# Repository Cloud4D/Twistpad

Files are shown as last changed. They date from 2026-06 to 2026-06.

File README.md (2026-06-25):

#  Twistpad
My submission for the Hack Club Hackpad project.

This repository contains all the files needed to produce a Twistpad, created by me. The Twistpad consists of a 3x3 grid of standard keys, which are bound to F13 - F21. On the right side of the grid, there are two dials, and the top one is bound to volume while the bottom one is bound to video controls (forward, backward, etc.). Additionally, there are LEDs, because who doesn't like a little RGB? I created this project over the course of nearly two weeks, using KiCad for the PCB, Fusion360 for the case design, and VSCode and Python for the firmware. 

So without further adieu, I present... the Twistpad!

## The hackpad:
A wonderful side view to give you an idea of the height



And then a top view so you can look through the window in the top right! (that tiny thing took me quite a long time)



The hackpad consists of a simple case design, with filleted corners and cutouts in the top to provide psace for the keys and dials to poke through. I wanted to add some extra stuff, so I spend time on the USB cutout (pictured below) making it look good and having it have a little inwards slant. i also spend time making the window into the PCB, which displays the Seeeduino logo perfectly. 



## Schematic of the PCB:
Made on KiCad, it was quite fun and easy to make it, no need to worry about physical space and stuff. 



The glorious PCB itself:
Also made on KiCad, it was also fun to do this, once I learned about vias. Has thicker traces for the 5V lines. 



## The case itself
This image pictures both the top plate and bottom part of the case, seperated. They fit together using M3x16mm screws along with M3x5mx4mm heatset inserts through the 4 holes on each corner of the case. In total, there are only 2 printed parts, the top and the bottom.



## The Firmware
This hackpad uses KMK firmware, and it was coded on VSCode using Python. 

## The BOM
1x Seeed XIAO RP2040

11x through-hold 1N4148 Diodes

9x MX-Style Switches

2x EC11 Rotary Encoders

9x white (or really any color or design you want) DSA keycaps

9x SK6812 MINI-E LEDs

4x M3x16mm screws

4x M3x5mx4mm heatset inserts

## Controls and binds
Imagine a 3x3 grid

A B C

D E F

G H I

Key A is bound to F13

Key B is bound to F14

Key C is bound to F15

Key D is bound to F16

Key E is bound to F17

Key F is bound to F18

Key G is bound to F19

Key H is bound to F20

Key I is bound to F21

In addition to that, due to a lack of pins, clicking down on the top dial is also mapped to whatever Key C is mapped to, and clicking down on the bottom dial is mapped to whatever Key I is mapped to.
Turning the top dial controls the volume, and turning the bottom dial controls video progress, like going forward in the video or backwards.

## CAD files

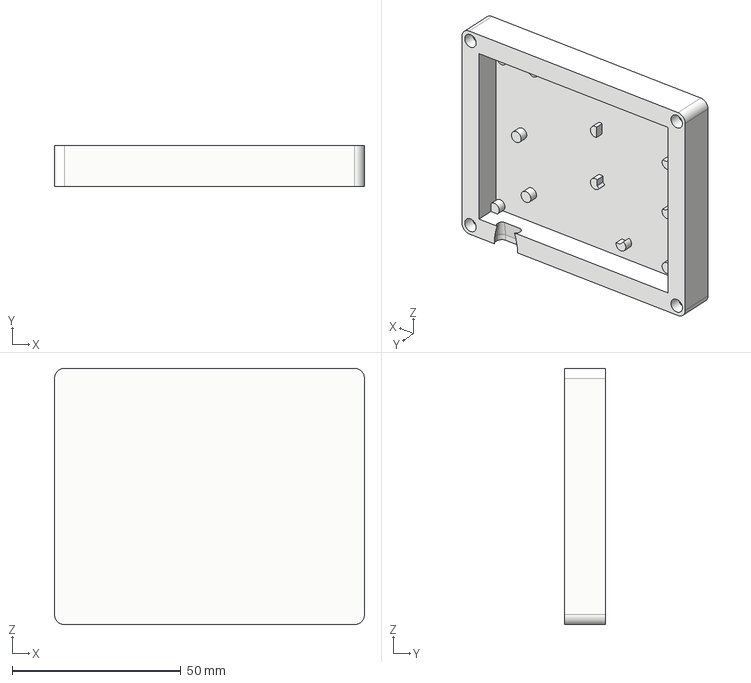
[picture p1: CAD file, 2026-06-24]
bottom.step
91.9 x 12.0 x 76.0 mm

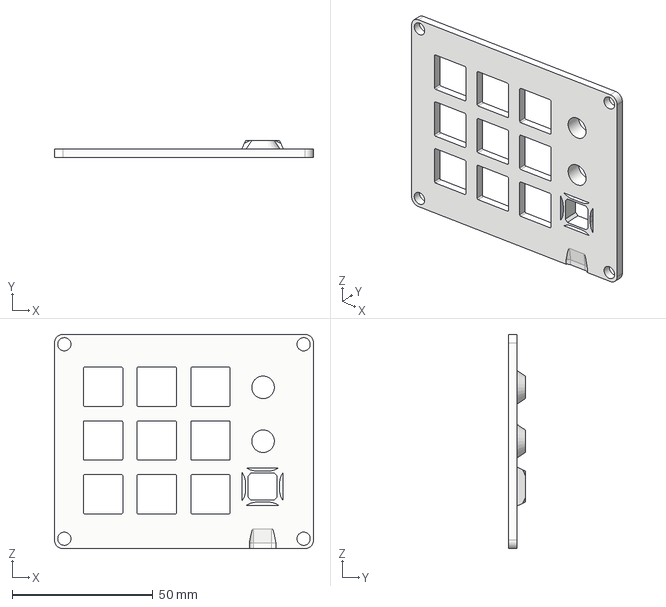
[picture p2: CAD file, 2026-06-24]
top.step
91.8 x 6.00 x 76.0 mm

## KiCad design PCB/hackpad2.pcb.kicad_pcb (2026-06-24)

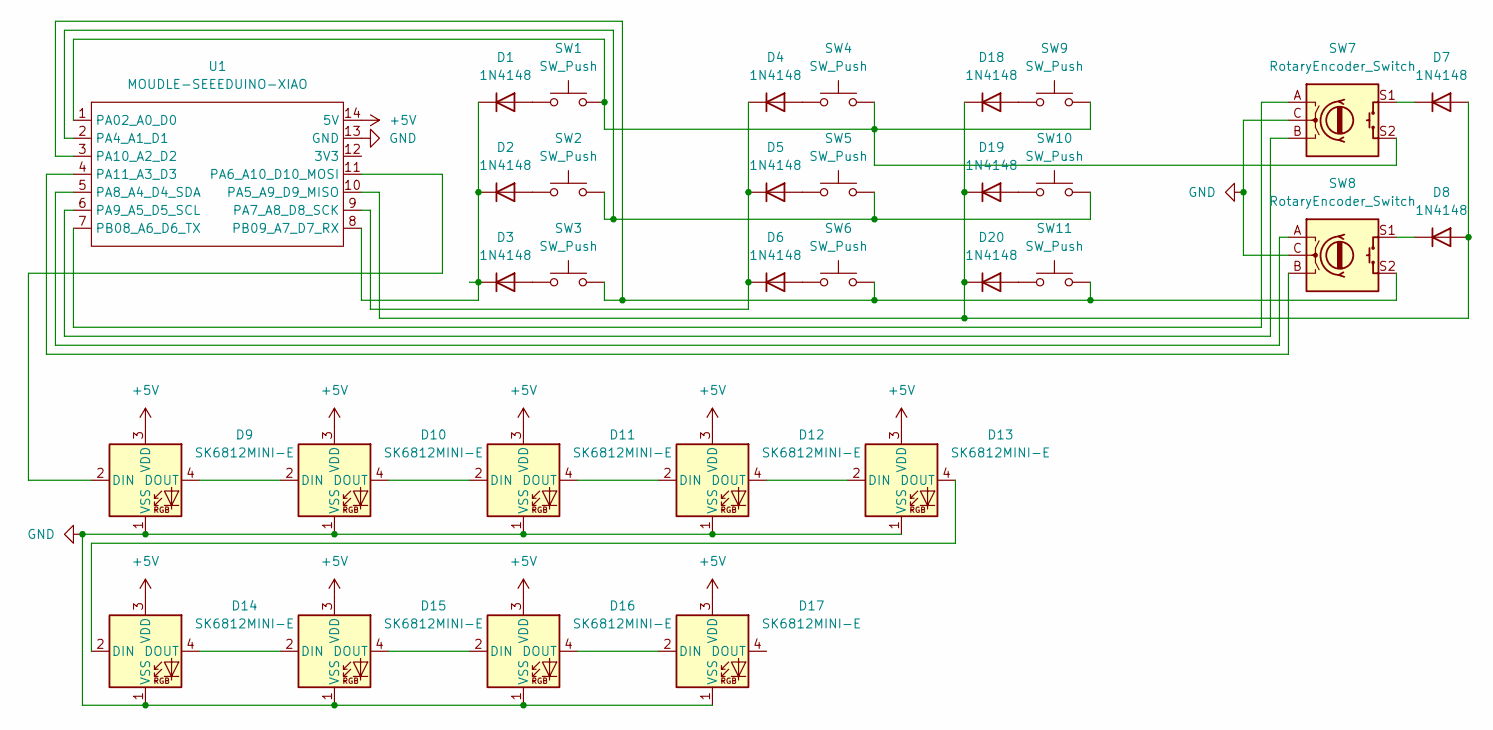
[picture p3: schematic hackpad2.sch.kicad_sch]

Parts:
D1, D2, D3, D4, D5, D6, D7, D8, D18, D19, D20: 1N4148; D_DO-35_SOD27_P7.62mm_Horizontal
D9, D10, D11, D12, D13, D14, D15, D16, D17: SK6812MINI-E; SK6812MINI-E_fixed
SW1, SW2, SW3, SW4, SW5, SW6, SW9, SW10, SW11: SW_Push; SW_Cherry_MX_1.00u_PCB
SW7, SW8: RotaryEncoder_Switch; RotaryEncoder_Alps_EC11E-Switch_Vertical_H20mm
U1: MOUDLE-SEEEDUINO-XIAO; XIAO-Generic-Hybrid-14P-2.54-21X17.8MM

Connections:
+5V: D9.3 (VDD), D10.3 (VDD), D11.3 (VDD), D12.3 (VDD), D13.3 (VDD), D14.3 (VDD), D15.3 (VDD), D16.3 (VDD), D17.3 (VDD), U1.14 (5V)
GND: D9.1 (VSS), D10.1 (VSS), D11.1 (VSS), D12.1 (VSS), D13.1 (VSS), D14.1 (VSS), D15.1 (VSS), D16.1 (VSS), D17.1 (VSS), SW7.C, SW8.C, U1.13 (GND)
unnamed: D1.2 (A), SW1.1
unnamed: D1.1 (K), D2.1 (K), D3.1 (K), U1.8 (PB09_A7_D7_RX)
unnamed: D2.2 (A), SW2.1
unnamed: D3.2 (A), SW3.1
unnamed: D4.2 (A), SW4.1
unnamed: D4.1 (K), D5.1 (K), D6.1 (K), U1.9 (PA7_A8_D8_SCK)
unnamed: D5.2 (A), SW5.1
unnamed: D6.2 (A), SW6.1
unnamed: D7.1 (K), SW7.S1
unnamed: D8.1 (K), SW8.S1
unnamed: D9.2 (DIN), U1.11 (PA6_A10_D10_MOSI)
unnamed: D9.4 (DOUT), D10.2 (DIN)
unnamed: D10.4 (DOUT), D11.2 (DIN)
unnamed: D11.4 (DOUT), D12.2 (DIN)
unnamed: D12.4 (DOUT), D13.2 (DIN)
unnamed: D13.4 (DOUT), D14.2 (DIN)
unnamed: D14.4 (DOUT), D15.2 (DIN)
unnamed: D15.4 (DOUT), D16.2 (DIN)
unnamed: D16.4 (DOUT), D17.2 (DIN)
unnamed: D18.2 (A), SW9.1
unnamed: D7.2 (A), D8.2 (A), D18.1 (K), D19.1 (K), D20.1 (K), U1.10 (PA5_A9_D9_MISO)
unnamed: D19.2 (A), SW10.1
unnamed: D20.2 (A), SW11.1
unnamed: SW1.2, SW4.2, SW7.S2, SW9.2, U1.1 (PA02_A0_D0)
unnamed: SW2.2, SW5.2, SW10.2, U1.2 (PA4_A1_D1)
unnamed: SW8.A, U1.5 (PA8_A4_D4_SDA)
unnamed: SW7.B, U1.6 (PA9_A5_D5_SCL)
unnamed: SW3.2, SW6.2, SW8.S2, SW11.2, U1.3 (PA10_A2_D2)
unnamed: SW8.B, U1.4 (PA11_A3_D3)
unnamed: SW7.A, U1.7 (PB08_A6_D6_TX)

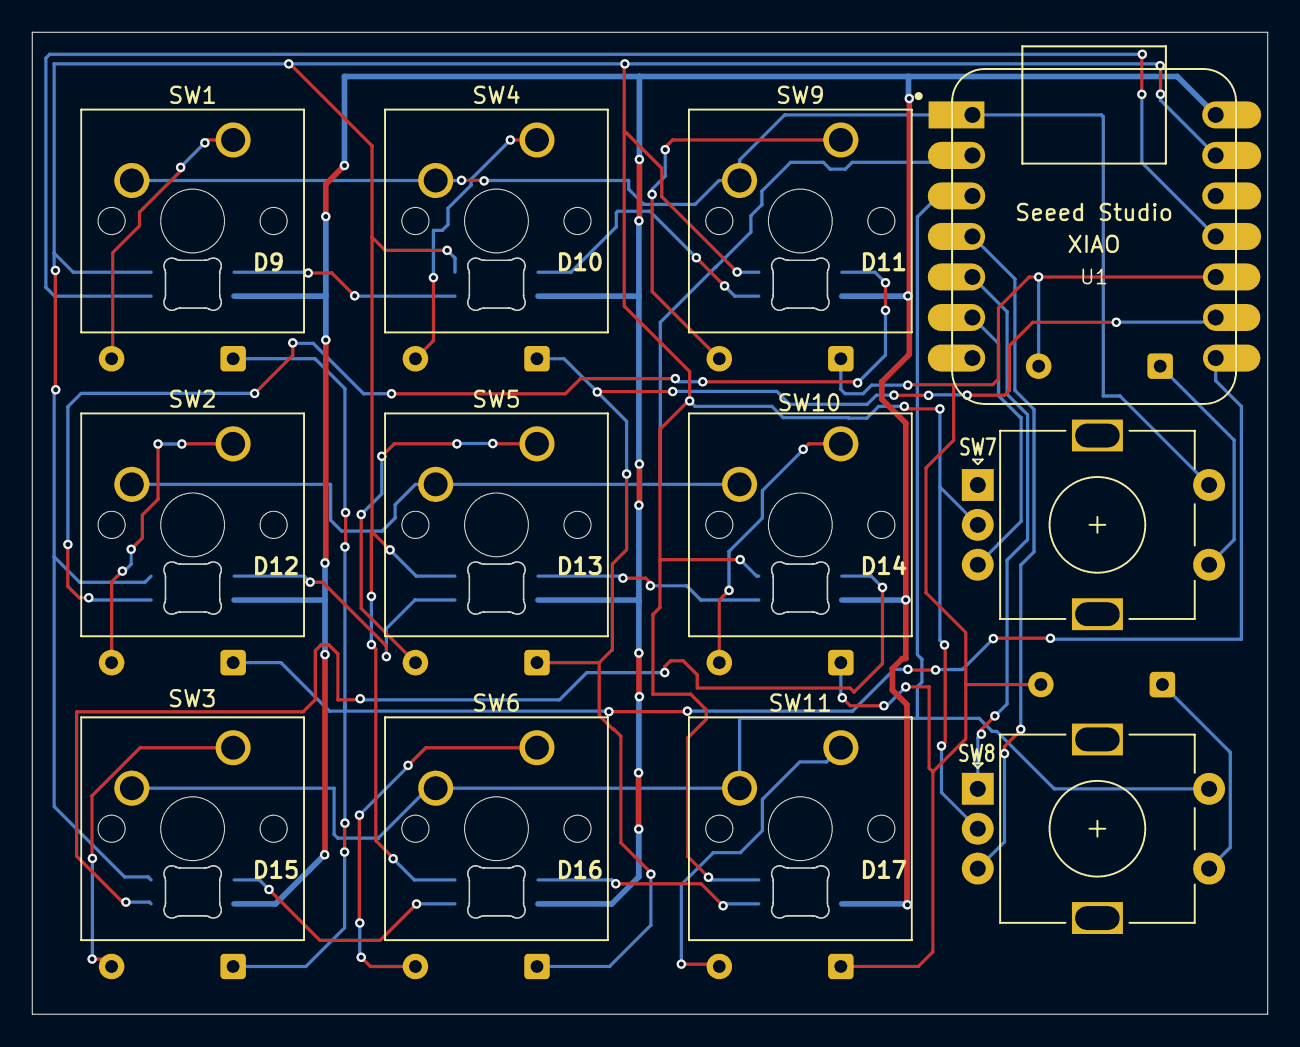
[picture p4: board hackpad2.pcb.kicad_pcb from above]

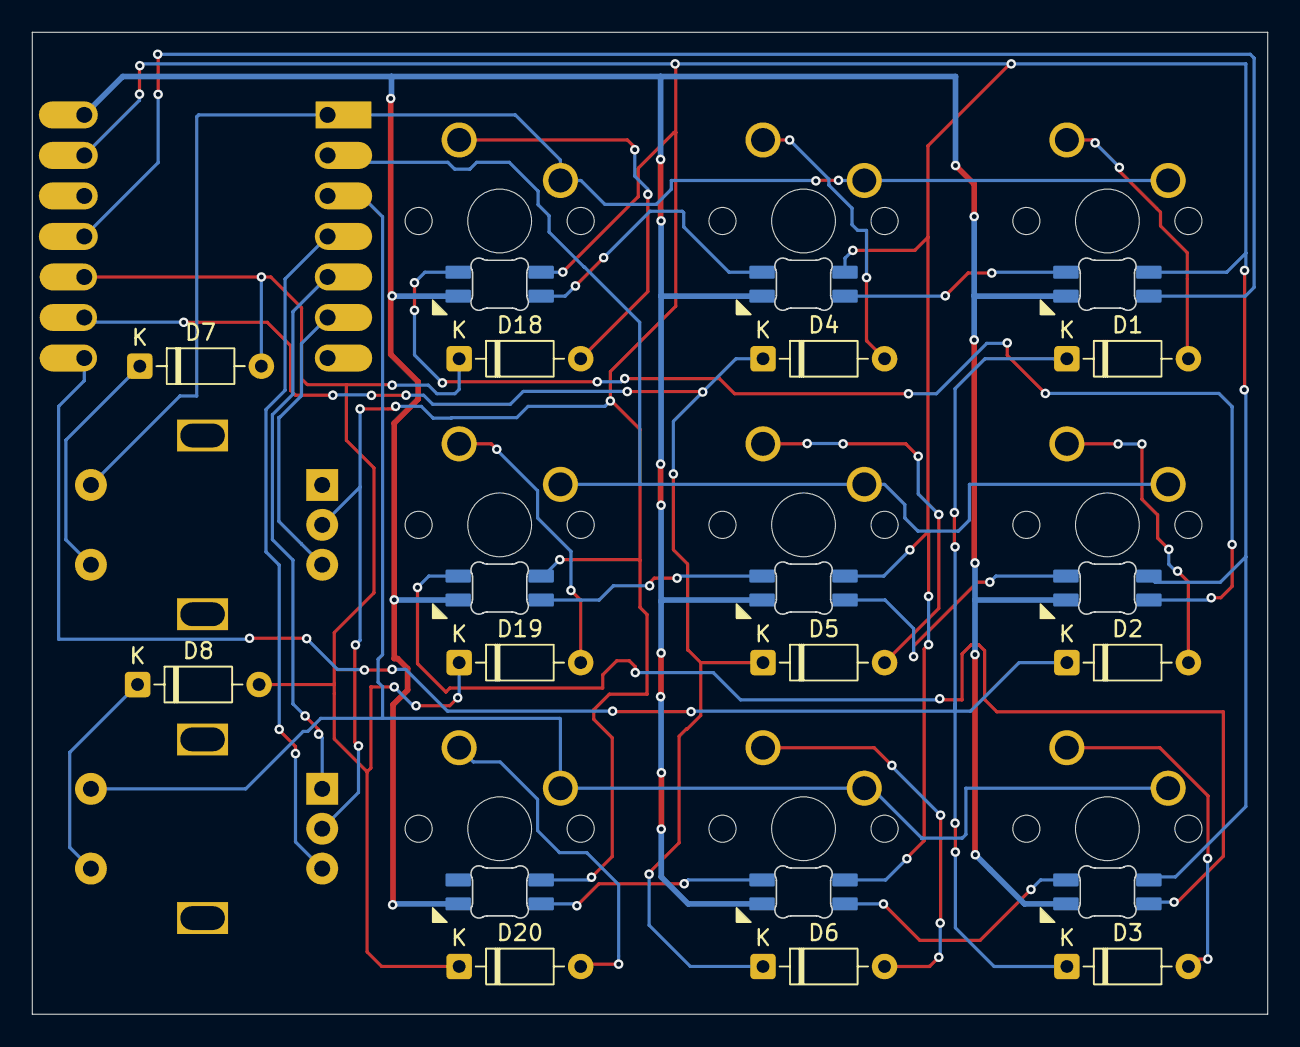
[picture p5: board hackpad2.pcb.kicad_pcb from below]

Board: 2 copper layers, 77.4 x 61.6 mm, 32 parts (11 on the bottom side), 32 nets.

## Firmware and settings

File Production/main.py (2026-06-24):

import board
from kmk.kmk_keyboard import KMKKeyboard
from kmk.keys import KC
from kmk.scanners import DiodeOrientation
from kmk.modules.encoder import EncoderHandler
from kmk.extensions.rgb import RGB

# keyboard brain
keyboard = KMKKeyboard()

# mapping the rows and columns and pins
keyboard.row_pins = (board.D0, board.D1, board.D2)
keyboard.col_pins = (board.D7, board.D8, board.D9,)
keyboard.diode_orientation = DiodeOrientation.ROW2COL

# intializing the rotary dial handlers
encoder_handler = EncoderHandler()
keyboard.modules.append(encoder_handler)
encoder_handler.divisor = 4  # changes sensitivity

# configuring the rotary dial pins
encoder_handler.pins = (
    (board.D6, board.D5, None, False),
    (board.D4, board.D3, None, False),
)

# rgb
rgb = RGB(pixel_pin=board.D10, num_pixels=9)
keyboard.extensions.append(rgb)

# defining the keys
keyboard.keymap = [
    [
        KC.F13, KC.F14, KC.F15, # sw1, sw4, sw9, 
        KC.F16, KC.F17, KC.F18, # sw2, sw5, sw10, 
        KC.F19, KC.F20, KC.F21, # sw3, sw6, sw11, 
    ]
]

# defining the dials
encoder_handler.map = [
    (
        (KC.VOLD, KC.VOLU),
        (KC.LEFT, KC.RGHT)
    )
]

#startup loop
if __name__ == "__main__":
    keyboard.go()

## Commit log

2026-06-24 All of my files for this project
    Includes production files, PCB files, and firmware. CAD files would not fit, but the seperated files for the case are in the Production folder.
    [bottom.step, hackpad2.pcb.kicad_pcb, hackpad2.sch.kicad_sch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]
2026-06-24 Enhance README with additional project details
    Added details about LEDs, case design, and BOM.
2026-06-25 Update README with firmware details and case description
    Added a new section about the firmware and clarified the case parts description.
2026-06-25 CAD Files
    Unfortunately the full CAD model is too big to fit in Github (over the 25mb limit) so I was forced to only send the top and bottom of the case.
    [bottom.step, top.step]
